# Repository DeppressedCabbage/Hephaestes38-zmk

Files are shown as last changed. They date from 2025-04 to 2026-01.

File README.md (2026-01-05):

<h1 align="left">Hephaestes38</h1>

Hephaestes38 is a custom, 38 key, low profile, split unibody keyboard. I Intended it to be used with the Hands Down promethium layout, but that's really up to you! ZMK studio has also been integrated, so it's super easy to make any changes you wish. See the [writeup](https://github.com/DeppressedCabbage/Hephaestes38-zmk/blob/main/Keymap.md) on Hands Down Promethium and my specific combos/layers. I only use 3 Layers, but the firmware has a total of 5 for you to add any you like. 

****


It's programmed on a Nice!Nano for wireless functonality, as well as compatibility for a Nice!View E-paper display to keep track of layers, battery status, or whatever else suits your fancy.



***
### PCB's
All files to make your own pcb's can be found in the pcb's and cases folder. The Hepheaestes38_PCB-Gerbers.zip can be uploaded into any pcb manufacturer to get them made, and all of the kicad files are available if you want to make any edits. If you are looking for an assembled PCB, reach out to me at conturakeyboards@gmail.com. A website will be coming soon if you would like to purchase pcb's or fully assembled keyboards. Stay tuned. 

***
### BOM

Additionally, you'll also need the following

- 38x SMD diodes (1N4148W)
- 38x Kailh Choc Hotswap Sockets
- 38x Kailh Choc V1 Switches
- 1x Nice!Nano
- 2× Pair of headers and sockets for the N!N (I used the easy solder machine headers, but mil-max sockets will work just fine too)
- (optional) 1x Nice!View
- (optional) 1x Lipo battery (301230)
- (optional) 1x Power switch (PCM12)
- (optional) 1x Reset switch (PTS526)
- (optional) Rubber feet to stop the keyboard sliding around (I used 3mm by 10mm ones, but if you aren't using a case it shouldn't matter much)

***
### Firmware

Hepheaestes38 runs ZMK, you can modify and compile you're own firmware by cloning the repo and making any edits you like. 

*** 
### V1 Case

This is the first version of they keyboard, and I forgot to add mounting holes to the pcb to facilitate Case attachement. I worked around this in a less than elegant way, and if you want to make v1 you would have to do something similar. Pictures are below. 




### V2 Case

Version 2 of the pcb and case are currently in progress, please follow for updates coming soon. In the meantime, here are some renders for your viewing pleasure. 
Hepheaestes38v2 Stylized ISO
Hepheaestes38v2 Top down 45

***
### To Do List

- ✔Create Case
- ✔Add via's to the pcb to facilitate Case attachement
- ✔Refine Pcb to allow for diode attachment on both sides, along with turning Diode Footprint around
- Lower profile?
- ✔ Add zmk Studio support
- Order V2 pcb's to confirm fitment

***
### Credits

This is my first foray into making my own keyboard, so special thanks go out to the entire ergo community, notably 

- [FlatFootFox](https://twitter.com/flatfootfox) - for the guide to ergogen
- [Ceoloide](https://github.com/ceoloide) - For the footprints used in creating the pcb
- [Lesshonor](https://github.com/lesshonor) - For helping me out with the getting the display to work
- And my lovely offline support system for moral support and encouragement.

***

## LICENSING
<picture align="left">
  
</picture>

This work is licensed under a
Creative Commons (4.0 International License)
Attribution—Noncommercial—Share Alike

- ✖ | Sharing without ATTRIBUTION
- ✔ | Remix Culture allowed
- ✖ | Commercial Use
- ✖ | Free Cultural Works
- ✖ | Meets Open Definition

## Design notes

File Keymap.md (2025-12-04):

<h1 align="left">Intro</h1>

### Hands Down
"Hands Down Layout variations were developed on a sound linguistic foundation (phonotactics) and an obsessive attention to corpus statistics using a variety of keyboard layout analyzers and methods that are all tested in live real-world situations to produce exceptionally comfortable long duration typing on modern keyboards." 
  - R. Alan Reiser
Who better to describe the layout than the very one who coined the layout and created such a strong foundation for the variation I landed on. Hands down layouts tend to yield extremely low SFBs, low redirects and low center column usage. This results in a very steady rythym when typing, creating a more comfortable, relaxed, and overall smoother experience.

### HD Promethium
I could personally never expect to explain the variation of the hands down layout as well as the two geniouses who first created it, u/phbonachi and u/RoastBeefer, so if you want an in depth writeup of the layout itself, please see [this](https://www.reddit.com/r/KeyboardLayouts/comments/1g66ivi/hands_down_promethium_snth_meets_hd_silverengram/) post. For a more high level overview, read ahead. 

A "SYNTH" and "AEI" home row help to make the in:out rolling ratio over 2:1, the H-Digrams have been maximized, pinky/ring scissors, same finger bigrams, lateral stretch, and center column usage have all been minimalized. 

HDPM Canonical layout

I had to modify my layout to work with the 38 keys on my keyboard, so it differs slightly from the "canonical" Layout pictured above. You can see the changes I made below. On a high level I moved the backspace key from the thumb cluster and replaced it with a oneshot shift key. Enter was also moved to a combo and replaced with the left alt, and the "Z" key was moved in place of the "/". TAB and Left CTR have been moved down in place of the "Backslash" key. 



### Layers and combos
A small keyboard is great, but if you only have alpha keys, it tends to not work the best for day to day productivity. To fix this, I use a Number and Symbol layer, as well as a dedicated Navigation layer. You can see them pictured below. To get to and from the layers, I use combos that utilize both the home row and the thumb. I found that this combination of fingers allows for very few false activations while still easily being activated when on purpose. 

To get to the Number Layer, the keys "E"and "Space" are used. ZMK studio doesn't like to show what is actually being sent to the computer sometimes, so this layout looks a bit odd. For example, on the left side of the keyboard you may notice some duplicate numbers, these are actualy sent to the computer with a modifier. You're left pinkey ("1") send an eclamation point, Left ring (/) sends a Qestion mark, Left middle and index ("9, 0") Send Parenthesis, and so on. 


"T" and "R" allow access to the navigation layer, and is the same as the number layer, just mirrored.

This layer also has bluetooth and screen controls, along with the ability to unlock ZMK studio so that you can make any changes you want in a GUI. Just as zmk studio doesn't display the correct modifiers, it also doesn't show keyboard controls. For that to be visualized you need to go into the actual keymap, but I will explain them all here. EP on, off, and tog all control the external power of the Nice!Nano, which in turn turns the screen on and off. BT_SEL will connect the keyboard to up to 5 different bluetooth profiles, meaning the keyboard could be connected to up to 5 different devices simultaneously. Lastly, the studio unlock key is used to unlock zmk studio, allowing changes to the keymap without the need to re-flash the firmware.


For those of you who would prefer to use the traditional QWERTY Layout, I have also added it into the keymap so that you can switch back and forth between this and the default HD Promethium. The combo "X"+"Backspace" is used to toggle this layer. The blank keys on this visualization are simply transparent, which means that it will just use they keys from the default layer, being Tab, Left control, Left Alt, Sticky Shift, and Space. 


I also have several empty layers that you can set up in zmk studio without having to mess with the keymap firmware. To unlock zmk studio, use the navigation layer and the "Studio Unlock" key ("M" Key on the alpha layer). These layers use the combo's "K"+",", and "J"+"-". To get back to the default alpha layer, you can press the same combo that got you to the layer to get out, as these combo's are set up as layer toggles. Alternatively, on the Number and Navigation Layers, you can hit the outermost thumb key on the right hand (Oneshot Shift key on the alpha layer) to get back to the default layer. I would recommend using this same key on all layers you add, as this really streamlines swithcing to and from the alpha layer.

You may have noticed that none of these layers contain common keys that we all use from day to day. For these keys, we use the combo's listed below. 

Enter is the index, middle and ring finger of the right hand resting in the home position ("A","E","I" on the alpha layer)
Escape is the index and middle finger of the left hand resting in the home position ("T", "H" on the alpha layer)
The OS Key is the ring an  index finger of the left hand resting in the home position ("N", "H" on the alpha layer)
Delete is the index ande middle finger of the left hand one row above the home position ("D", "L" on the alpha layer)

All of the modifier combos work on all layers, but all layer combo's do not work on all layers. ZMK firmware only allows for direct switching to a layer above, or going back to the default layer. Because of this, you can go from the Navigation layer up to the Number layer, but not from the Number layer down to the Navigation layer. You would need to go back to the alpha layer, and then to the Navigation layer from the Number layer.

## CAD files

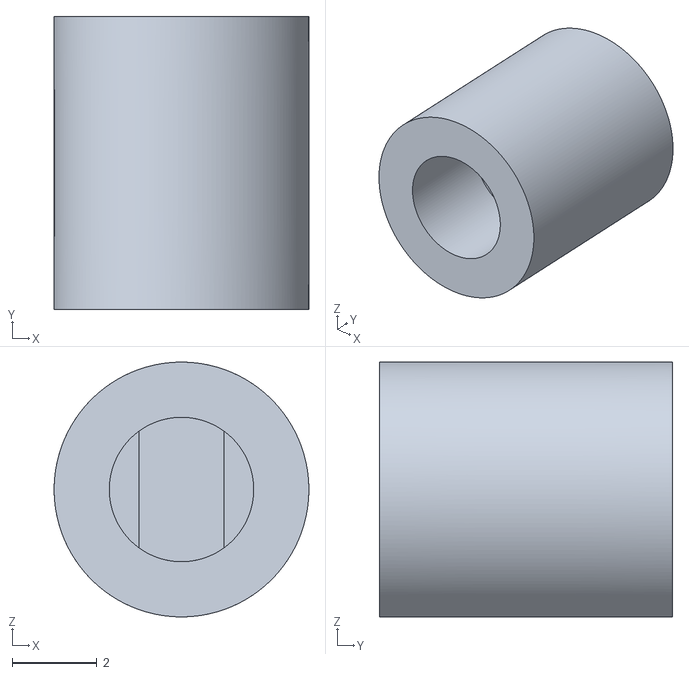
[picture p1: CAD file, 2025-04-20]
PCB, Case/Acrylic Case V1/Printed Standoff 6.9mm.stl
6.00 x 6.90 x 6.00

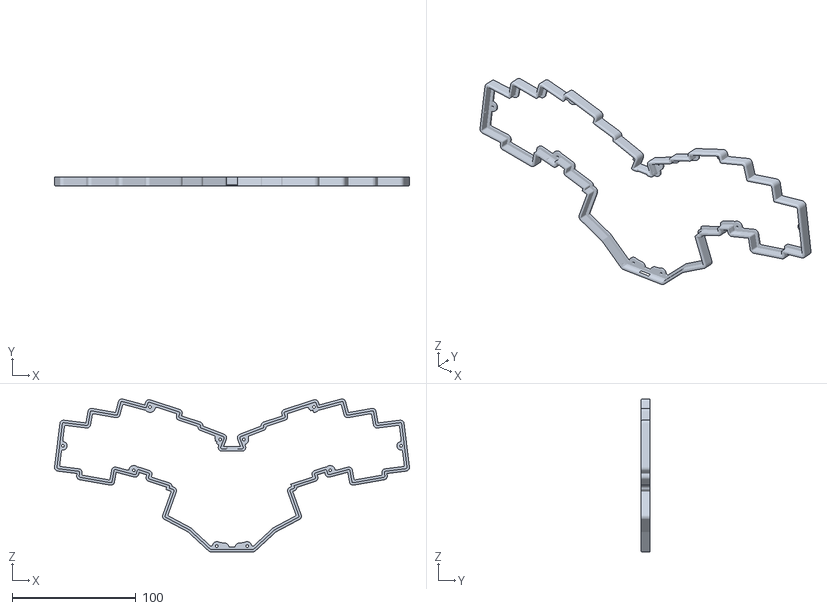
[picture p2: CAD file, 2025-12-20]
PCB, Case/Case V2/Manufacturing/Hephaestus38v2 Case Bottom Retrofit.stl
286.3 x 7.40 x 123.4

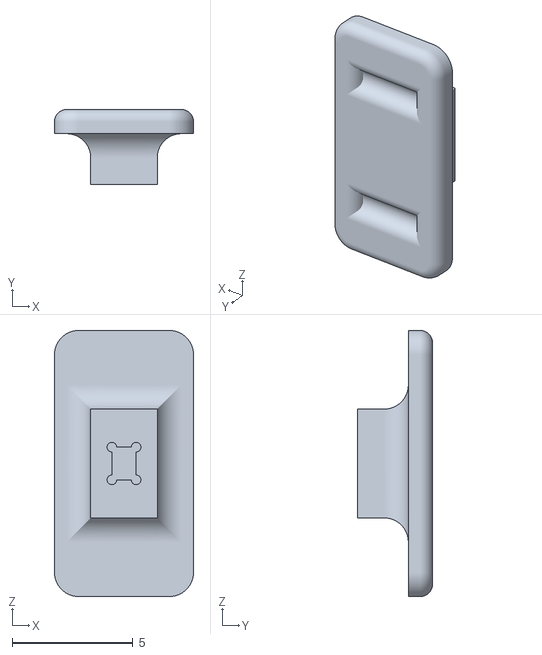
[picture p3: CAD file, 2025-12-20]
PCB, Case/Case V2/Power Switch.stl
5.75 x 3.10 x 11.0

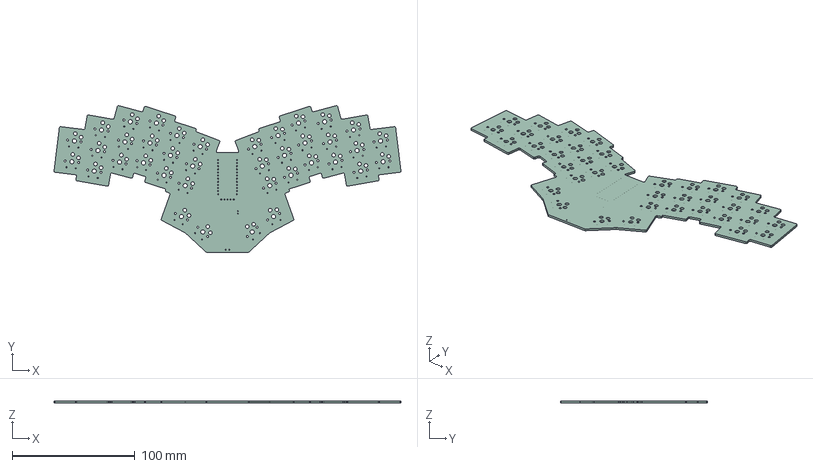
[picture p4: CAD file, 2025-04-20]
PCB, Case/kicad PCB files/Hepheaestes38_PCB/Hepheaestes38_PCB.step
282.3 x 119.4 x 1.60 mm

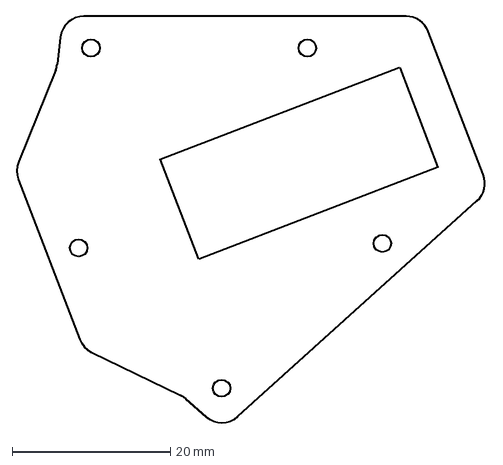
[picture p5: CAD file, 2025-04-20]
PCB, Case/Acrylic Case V1/Screen Cover.dxf
59.5 x 51.6 mm

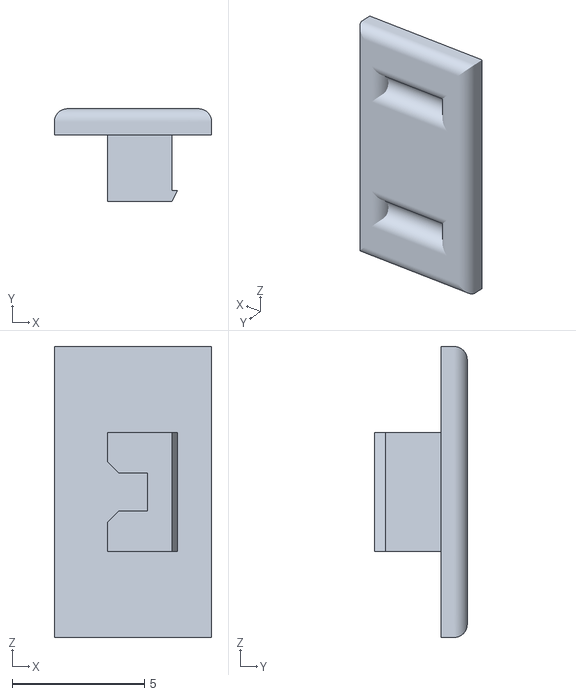
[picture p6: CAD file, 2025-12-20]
PCB, Case/Case V2/Manufacturing/Power Switch.stl
5.95 x 3.50 x 11.0

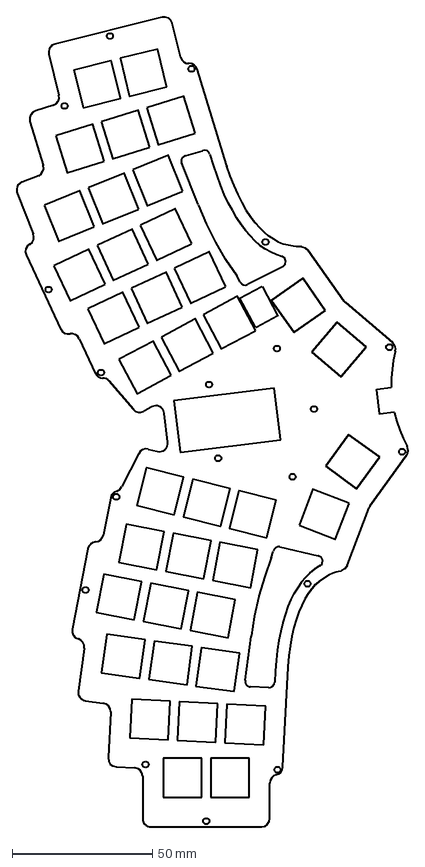
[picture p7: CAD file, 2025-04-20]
PCB, Case/Acrylic Case V1/Acrylic Top.dxf
139.9 x 289.0 mm

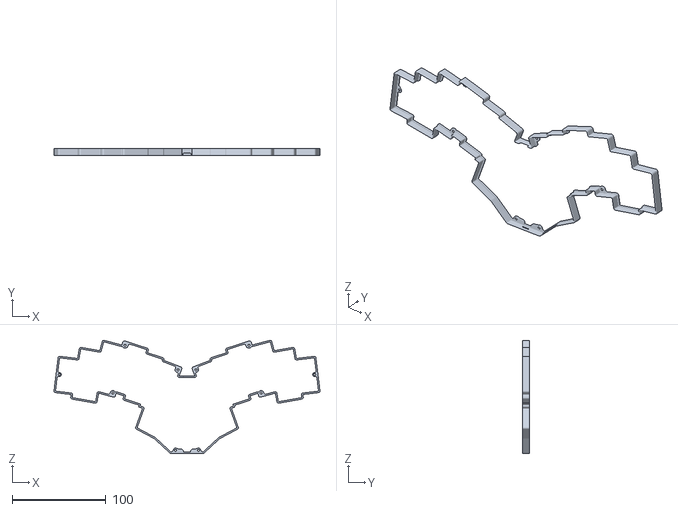
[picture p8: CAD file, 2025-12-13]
PCB, Case/Case V2/Manufacturing/Hephaestus38v2 Case Bottom.stl
283.9 x 7.40 x 121.0

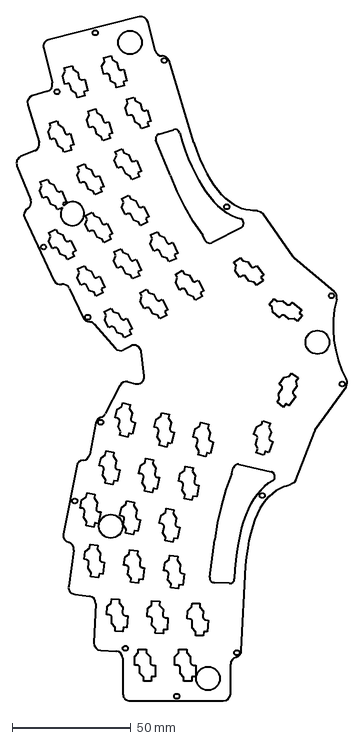
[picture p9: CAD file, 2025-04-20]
PCB, Case/Acrylic Case V1/Acrylic bottom.dxf
139.9 x 289.0 mm

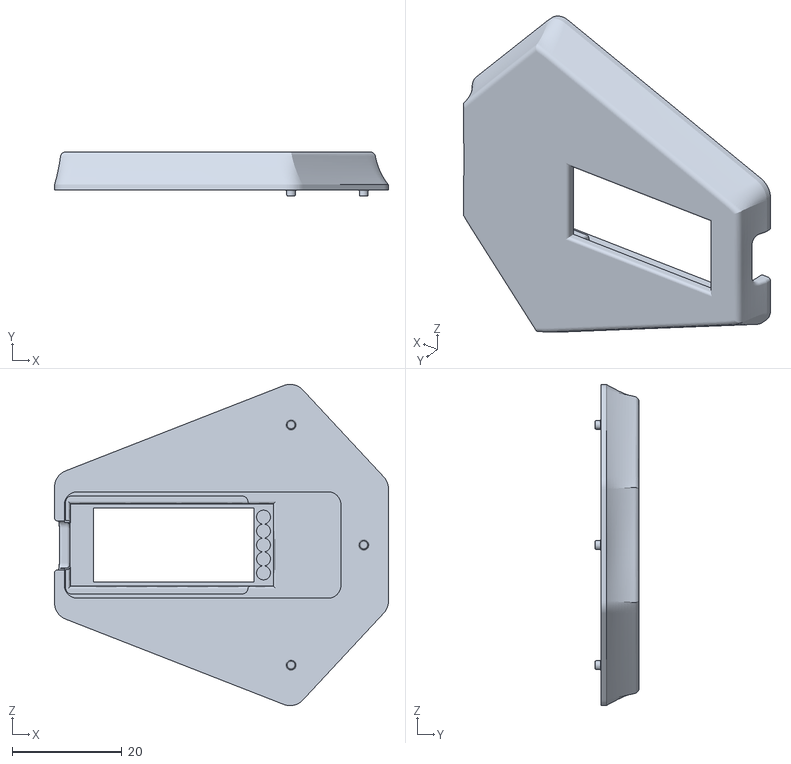
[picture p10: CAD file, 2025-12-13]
PCB, Case/Case V2/Manufacturing/Hephaestus38v2 Case Screen Cover Retrofit.stl
60.9 x 8.10 x 58.5

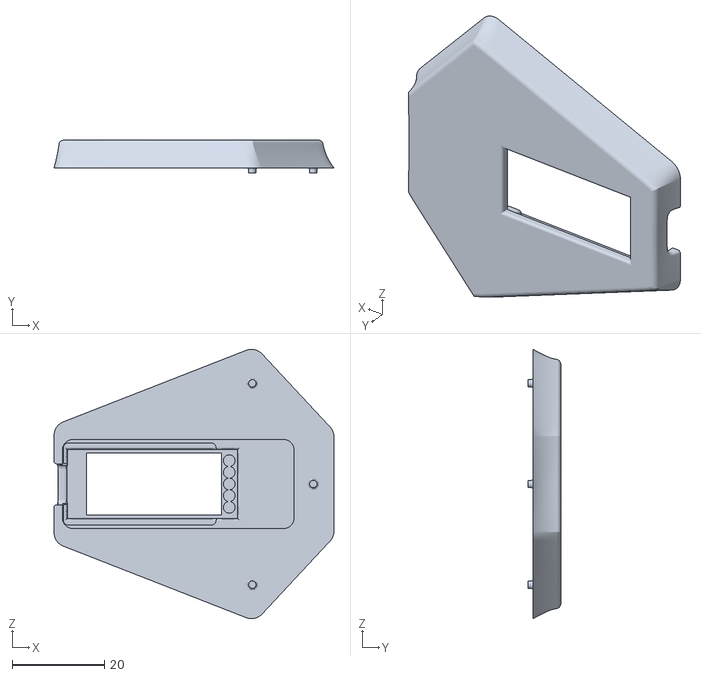
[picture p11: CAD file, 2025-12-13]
PCB, Case/Case V2/Manufacturing/Hephaestus38v2 Case Screen Cover V2.stl
60.9 x 7.10 x 58.5

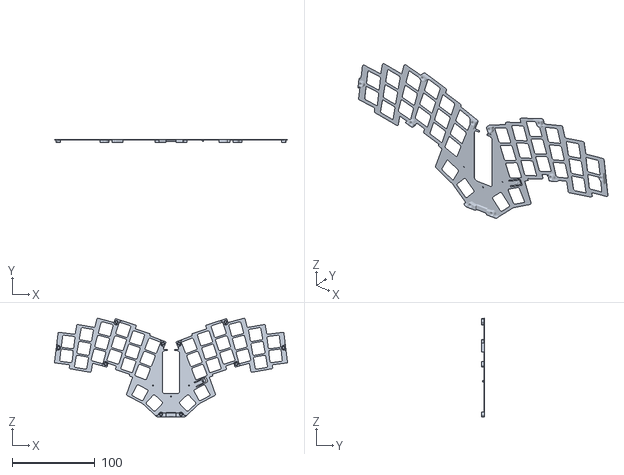
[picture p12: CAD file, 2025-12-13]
PCB, Case/Case V2/Manufacturing/Hephaestus38v2 Case Top V2.stl
282.3 x 4.00 x 119.4

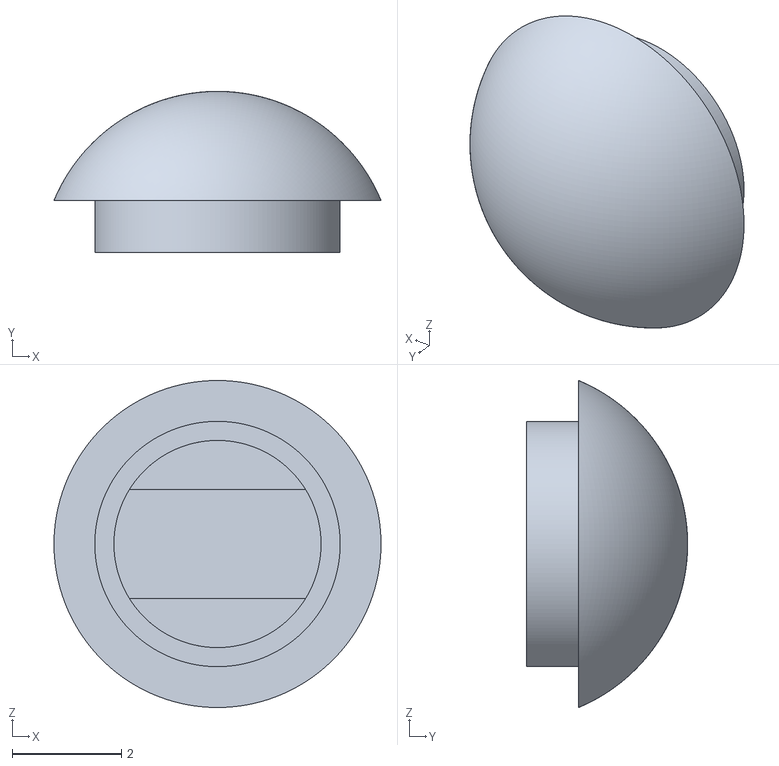
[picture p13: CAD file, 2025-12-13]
PCB, Case/Case V2/Manufacturing/Hephaestus38v2 Case Feet.stl
6.00 x 2.96 x 6.00

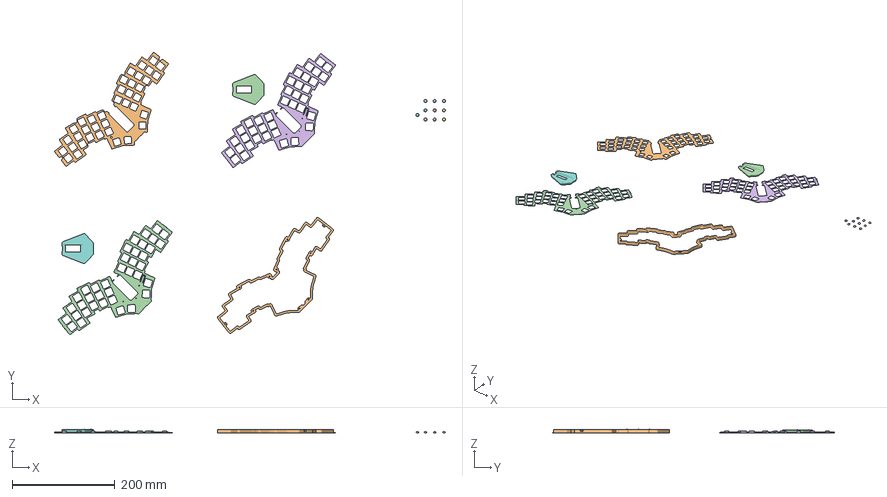
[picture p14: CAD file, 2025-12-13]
PCB, Case/Case V2/Manufacturing/Hephaestus Case v2.3mf
761.1 x 549.8 x 8.10 mm
Hephaestus38v2 Case Feet.stl x 10
Hephaestus38v2 Switchplate.stl
Hephaestus38v2 Case Screen Cover V2.stl
Hephaestus38v2 Case Top V2.stl
Hephaestus38v2 Case Screen Cover Retrofit.stl
Hephaestus38v2 Case Bottom Retrofit.stl
Hephaestus38v2 Case Top V2 Retrofit.stl

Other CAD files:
PCB, Case/Case V2/Manufacturing/Hephaestus38v2 Case Top V2 Retrofit.stl
PCB, Case/Case V2/Manufacturing/Hephaestus38v2 Switchplate.stp
PCB, Case/Acrylic Case V1/Acrylic Top.ipt
PCB, Case/Acrylic Case V1/Acrylic bottom.ipt
PCB, Case/Acrylic Case V1/Hepheaestes38_Case_Assy.iam
PCB, Case/Acrylic Case V1/OldVersions/Acrylic Top.0009.ipt
PCB, Case/Acrylic Case V1/OldVersions/Acrylic bottom.0009.ipt
PCB, Case/Acrylic Case V1/OldVersions/Hepheaestes38_Case_Assy.0015.iam
PCB, Case/Acrylic Case V1/OldVersions/Printed Standoff 6.9mm.0002.ipt
PCB, Case/Acrylic Case V1/OldVersions/Screen Cover.0004.ipt
PCB, Case/Acrylic Case V1/Printed Standoff 6.9mm.ipt
PCB, Case/Acrylic Case V1/Screen Cover.ipt
PCB, Case/Case V2/Carry Case.ipt
PCB, Case/Case V2/Hephaestus38v2 Case Bottom.ipt
PCB, Case/Case V2/Hephaestus38v2 Case Feet.ipt
PCB, Case/Case V2/Hepheaestes38v2 CAD/Hepheaestes38v2.iam
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

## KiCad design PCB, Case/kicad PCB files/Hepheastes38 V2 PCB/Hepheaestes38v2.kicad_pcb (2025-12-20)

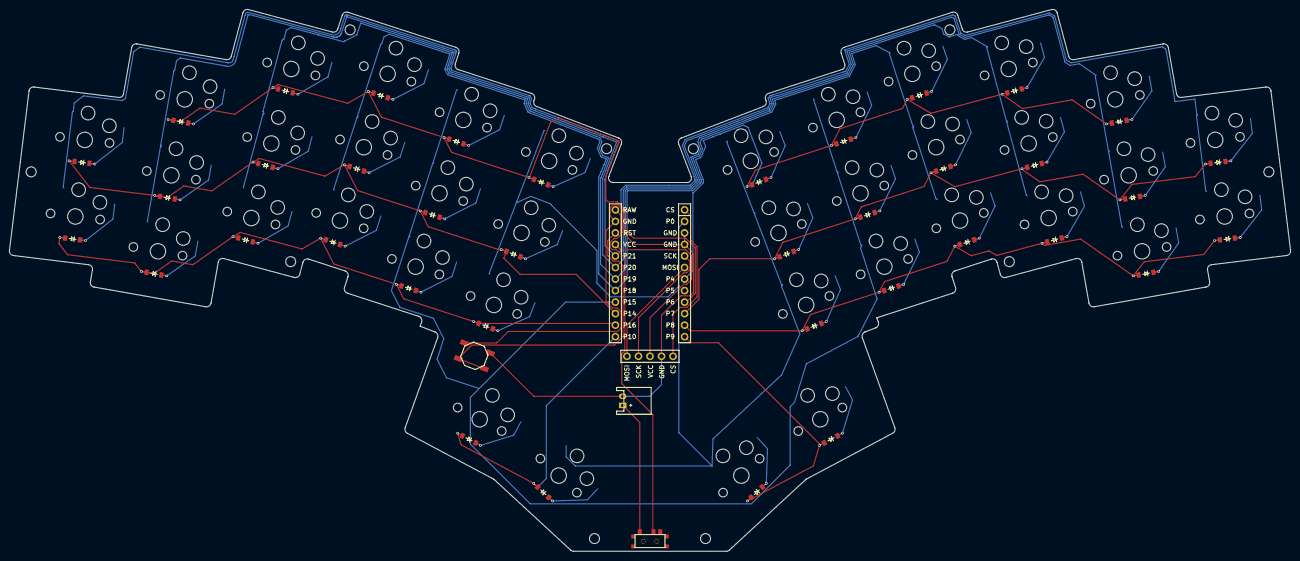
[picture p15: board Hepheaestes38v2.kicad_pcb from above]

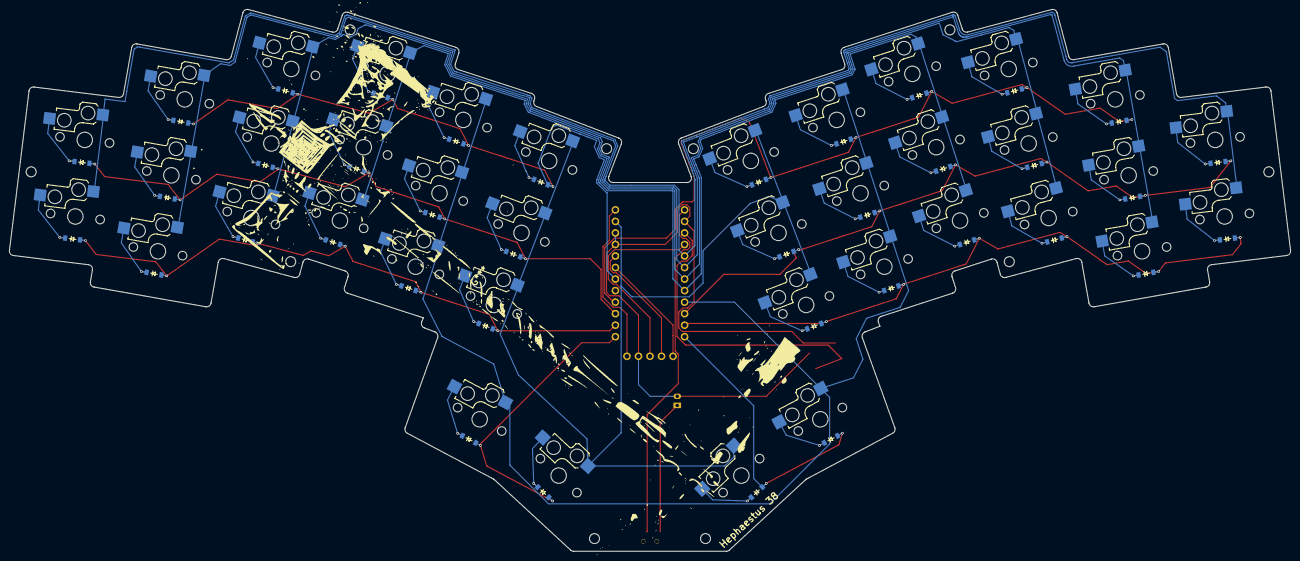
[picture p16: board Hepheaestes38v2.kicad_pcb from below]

Board: 2 copper layers, 282.3 x 119.4 mm, 91 parts (38 on the bottom side), 60 nets.

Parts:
B1: SW_TACT_ALPS_SKQGABE010
D1, D2, D3, D4, D5, D6, D7, D8, D9, D10, D11, D12, D13, D14, D15, D16, D17, D18, D19, D20, D21, D22, D23, D24, D25, D26, D27, D28, D29, D30, D31, D32, D33, D34, D35, D36, D37, D38: diode_tht_sod123
DISP1: display_nice_view
JST1: JST_PH_S2B-PH-K_02x2.00mm_Angled
MCU1: mcu_nice_nano
MH1, MH2, MH3, MH4, MH5, MH6, MH7, MH8, MH9, MH10: mounting_hole_npth
S1, S2, S3, S4, S5, S6, S7, S8, S9, S10, S11, S12, S13, S14, S15, S16, S17, S18, S19, S20, S21, S22, S23, S24, S25, S26, S27, S28, S29, S30, S31, S32, S33, S34, S35, S36, S37, S38: switch_choc_v1_v2
T1: SPDT_C128955

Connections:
CS: DISP1.5, MCU1.1
GND: B1.1, DISP1.4, JST1.2, MCU1.3, MCU1.4, MCU1.23
MOSI: DISP1.1, MCU1.6
P0: MCU1.2, S15.1, S16.1, S17.1, S32.1, S33.1, S34.1, S36.1, S38.1
P4: D22.2, D25.2, D28.2, D31.2, D34.2, MCU1.7
P6: D5.2, D8.2, D11.2, D14.2, D17.2, MCU1.9
P7: D19.2, D21.2, D24.2, D27.2, D30.2, D33.2, MCU1.10
P8: D18.2, D20.2, D23.2, D26.2, D29.2, D32.2, MCU1.11
P9: D37.2, D38.2, MCU1.12
P10: D35.2, D36.2, MCU1.13
P14: D2.2, D4.2, D7.2, D10.2, D13.2, D16.2, MCU1.15
P15: MCU1.16, S12.1, S13.1, S14.1, S29.1, S30.1, S31.1, S35.1, S37.1
P16: D1.2, D3.2, D6.2, D9.2, D12.2, D15.2, MCU1.14
P18: MCU1.17, S9.1, S10.1, S11.1, S26.1, S27.1, S28.1
P19: MCU1.18, S6.1, S7.1, S8.1, S23.1, S24.1, S25.1
P20: MCU1.19, S3.1, S4.1, S5.1, S20.1, S21.1, S22.1
P21: MCU1.20, S1.1, S2.1, S18.1, S19.1
RAW: MCU1.24, T1.2
RST: B1.2, MCU1.22
SCK: DISP1.2, MCU1.5
VCC: DISP1.3, MCU1.21
index_bottom: D12.1, S12.2
index_home: D13.1, S13.2
index_top: D14.1, S14.2
inner_bottom: D15.1, S15.2
inner_home: D16.1, S16.2
inner_top: D17.1, S17.2
middle_bottom: D9.1, S9.2
middle_home: D10.1, S10.2
middle_top: D11.1, S11.2
mirror_index_bottom: D29.1, S29.2
mirror_index_home: D30.1, S30.2
mirror_index_top: D31.1, S31.2
mirror_inner_bottom: D32.1, S32.2
mirror_inner_home: D33.1, S33.2
mirror_inner_top: D34.1, S34.2
mirror_middle_bottom: D26.1, S26.2
mirror_middle_home: D27.1, S27.2
mirror_middle_top: D28.1, S28.2
mirror_outer_bottom: D18.1, S18.2
mirror_outer_home: D19.1, S19.2
mirror_pinky_bottom: D20.1, S20.2
mirror_pinky_home: D21.1, S21.2
mirror_pinky_top: D22.1, S22.2
mirror_reachy_thumbrow: D38.1, S38.2
mirror_ring_bottom: D23.1, S23.2
mirror_ring_home: D24.1, S24.2
mirror_ring_top: D25.1, S25.2
mirror_tucky_thumbrow: D37.1, S37.2
outer_bottom: D1.1, S1.2
outer_home: D2.1, S2.2
pinky_bottom: D3.1, S3.2
pinky_home: D4.1, S4.2
pinky_top: D5.1, S5.2
pos: JST1.1, T1.1
reachy_thumbrow: D36.1, S36.2
ring_bottom: D6.1, S6.2
ring_home: D7.1, S7.2
ring_top: D8.1, S8.2
tucky_thumbrow: D35.1, S35.2

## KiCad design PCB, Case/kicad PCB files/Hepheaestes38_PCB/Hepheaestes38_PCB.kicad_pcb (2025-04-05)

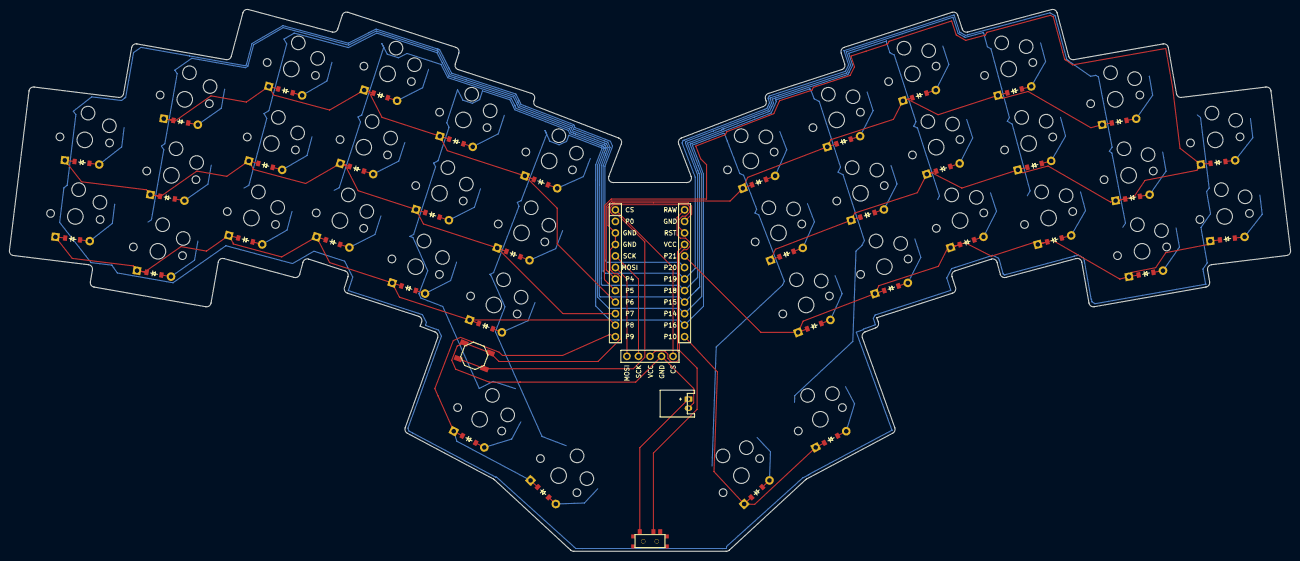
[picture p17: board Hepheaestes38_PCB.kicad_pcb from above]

Board: 2 copper layers, 282.3 x 119.4 mm, 81 parts (0 on the bottom side), 60 nets.

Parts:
B1: SW_TACT_ALPS_SKQGABE010
D1, D2, D3, D4, D5, D6, D7, D8, D9, D10, D11, D12, D13, D14, D15, D16, D17, D18, D19, D20, D21, D22, D23, D24, D25, D26, D27, D28, D29, D30, D31, D32, D33, D34, D35, D36, D37, D38: ComboDiode
DISP1: display_nice_view
JST1: JST_PH_S2B-PH-K_02x2.00mm_Angled
MCU1: mcu_nice_nano
S1, S2, S3, S4, S5, S6, S7, S8, S9, S10, S11, S12, S13, S14, S15, S16, S17, S18, S19, S20, S21, S22, S23, S24, S25, S26, S27, S28, S29, S30, S31, S32, S33, S34, S35, S36, S37, S38: PG1350
T1: SPDT_C128955

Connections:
CS: DISP1.5, MCU1.24
GND: B1.1, DISP1.4, JST1.2, MCU1.2, MCU1.21, MCU1.22
MOSI: DISP1.1, MCU1.19
P4: D22.1, D25.1, D28.1, D31.1, D34.1, MCU1.18
P5: D19.1, D21.1, D24.1, D27.1, D30.1, D33.1, MCU1.17
P6: D5.1, D8.1, D11.1, D14.1, D17.1, MCU1.16
P7: D2.1, D4.1, D7.1, D10.1, D13.1, D16.1, MCU1.15
P8: D1.1, D3.1, D6.1, D9.1, D12.1, D15.1, MCU1.14
P9: D35.1, D36.1, MCU1.13
P10: D37.1, D38.1, MCU1.12
P14: MCU1.10, S12.1, S13.1, S14.1, S29.1, S30.1, S31.1, S35.1, S37.1
P15: MCU1.9, S9.1, S10.1, S11.1, S26.1, S27.1, S28.1
P16: MCU1.11, S15.1, S16.1, S17.1, S32.1, S33.1, S34.1, S36.1, S38.1
P18: MCU1.8, S6.1, S7.1, S8.1, S23.1, S24.1, S25.1
P19: MCU1.7, S3.1, S4.1, S5.1, S20.1, S21.1, S22.1
P20: MCU1.6, S1.1, S2.1, S18.1, S19.1
P21: D18.1, D20.1, D23.1, D26.1, D29.1, D32.1, MCU1.5
RAW: MCU1.1, T1.2
RST: B1.2, MCU1.3
SCK: DISP1.2, MCU1.20
VCC: DISP1.3, MCU1.4
index_bottom: D12.2, S12.2
index_home: D13.2, S13.2
index_top: D14.2, S14.2
inner_bottom: D15.2, S15.2
inner_home: D16.2, S16.2
inner_top: D17.2, S17.2
middle_bottom: D9.2, S9.2
middle_home: D10.2, S10.2
middle_top: D11.2, S11.2
mirror_index_bottom: D29.2, S29.2
mirror_index_home: D30.2, S30.2
mirror_index_top: D31.2, S31.2
mirror_inner_bottom: D32.2, S32.2
mirror_inner_home: D33.2, S33.2
mirror_inner_top: D34.2, S34.2
mirror_middle_bottom: D26.2, S26.2
mirror_middle_home: D27.2, S27.2
mirror_middle_top: D28.2, S28.2
mirror_outer_bottom: D18.2, S18.2
mirror_outer_home: D19.2, S19.2
mirror_pinky_bottom: D20.2, S20.2
mirror_pinky_home: D21.2, S21.2
mirror_pinky_top: D22.2, S22.2
mirror_reachy_thumbrow: D38.2, S38.2
mirror_ring_bottom: D23.2, S23.2
mirror_ring_home: D24.2, S24.2
mirror_ring_top: D25.2, S25.2
mirror_tucky_thumbrow: D37.2, S37.2
outer_bottom: D1.2, S1.2
outer_home: D2.2, S2.2
pinky_bottom: D3.2, S3.2
pinky_home: D4.2, S4.2
pinky_top: D5.2, S5.2
pos: JST1.1, T1.1
reachy_thumbrow: D36.2, S36.2
ring_bottom: D6.2, S6.2
ring_home: D7.2, S7.2
ring_top: D8.2, S8.2
tucky_thumbrow: D35.2, S35.2

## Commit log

2025-03-22 fixed pin callouts
2025-03-22 Removed layer filters on combos
2025-04-03 Update Thumb row pin in Ergogen.yml
2025-04-03 added kicad pcb files
    [Hepheaestes38_PCB.kicad_pcb]
2025-04-03 General organisation
    [Hepheaestes38_PCB.kicad_pcb]
2025-04-05 Added PCB Gerber Files
    [Hepheaestes38_PCB.kicad_pcb]
2025-04-10 Turned on external power
2025-04-10 added external power in kconfig
2025-04-10 added compatible in ext power management
2025-04-11 fixed external power callout
2025-04-11 changed pin layout
2025-04-19 Configured Custom Spi node for Nice!View
2025-04-19 Reorginized File structure
    [Hepheaestes38_PCB.kicad_pcb]
2025-04-20 Added zmk studio support
    [Acrylic Top.0008.ipt, Acrylic Top.dxf, Acrylic Top.ipt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]
2025-04-20 Moved physical layout back to overlay, added usb uart capability
2025-04-20 Show battery status as percentage instead of icon
2025-04-20 Added battery reporting in kconfig
2025-04-20 Added battery sensor driver in overlay
2025-04-20 Reformatted device tree
2025-04-20 fixed typo in device tree
2025-04-26 Updated Folder Structure, cleaned up case files
    [Acrylic Top.0008.ipt, Acrylic Top.0009.ipt, Acrylic Top.dxf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]
2025-04-27 Rotated Diodes so silkscreen shows correct orientation
2025-04-27 Update README.md to include pictures of the case
2025-11-22 Update Hephaestes38v2.yml
    Moved some of the mounting holes, updated yaml
2025-11-22 uploading new v2 pcb files
    [Hepheaestes38v2.kicad_pcb]
2025-11-22 Re-organised folder structure, adding v2 CAD
    [Hepheaestes38_PCB.kicad_pcb, Hepheaestes38_PCB.step, Hepheaestes38v2.0004.iam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]
2025-11-23 Updating V2 Case files
    [Hephaestus38v2 Case Bottom.0009.ipt, Hephaestus38v2 Case Bottom.ipt, Hephaestus38v2 Case Screen Cover.0013.ipt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]
2025-11-24 updating revised v2 case parts
    [Hephaestus38v2 Case Bottom.0009.ipt, Hephaestus38v2 Case Bottom.0010.ipt, Hephaestus38v2 Case Bottom.ipt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]
2025-12-13 Updating Case Components
    [Hephaestus Case v2.3mf, Hephaestus38v2 Case Bottom Retrofit.stl, Hephaestus38v2 Case Bottom.0010.ipt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]
2025-12-13 Reorignized file structure
    [Hephaestus Case v2.3mf, Hephaestus38v2 Case Bottom Retrofit.stl, Hephaestus38v2 Case Bottom.0024.ipt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]
2025-12-20 Revised PCBv2 Gerber And files
    [Hephaestus38v2 Case Bottom Retrofit.stl, Hepheaestes38v2.kicad_pcb, Power Switch.0001.ipt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]
2025-12-20 Made changes to the case files
    [Hephaestus38v2 Case Bottom Retrofit.stl]
2025-12-26 added bluetooth clear profile key
    [Carry Case.0001.ipt, Carry Case.ipt]
